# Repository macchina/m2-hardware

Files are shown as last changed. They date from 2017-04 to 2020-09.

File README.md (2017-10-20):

# Macchina M2

The Macchina M2 is a open-source, programmable interface with hardware support for most automotive protocols including CAN, SWCAN, LIN, J1850PWM, ISO9141, and KWP2000.

This repository contains open sourced files for to the M2 hardware.  The **M2** folder contains files for the retail version of the M2.  The **M2-B** contains the files for the beta board that was produced in limited numbers and sent to members of the Developer Program.

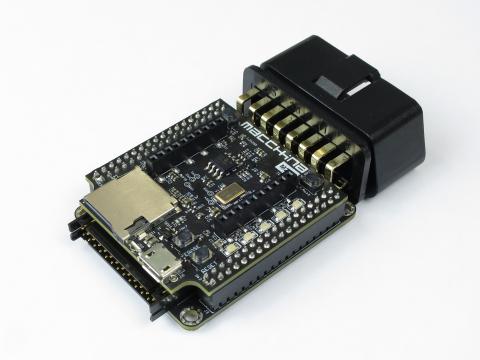
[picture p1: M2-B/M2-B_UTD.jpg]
Under-the-dash model


The under-the-dash model, pictured above, plugs into your car's OBD2 port.  The Macchina M2 is also available in an under-the-hood model.

The files in this repository are released under the [Creative Commons Attribution-ShareAlike 4.0 International (CC BY-SA) license](LICENSE).

To order visit https://www.macchina.cc/catalog

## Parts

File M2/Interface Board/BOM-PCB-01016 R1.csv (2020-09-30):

# | Quantity | PartType | Designator | Description | Footprint | MANUFACTURER | MANUFACTURER # | DISTRIBUTOR | DISTRIBUTOR #
1 | 2 | 9.0pF | C47, C48 | CAP CER 9.0PF 50V NP0 0402 | 0402_N2A-C | Murata Electronics North America | GRM1555C1H9R0CA01D | Digi-Key | 490-8232-1-ND
2 | 2 | 22pF | C17, C20 | CAP CER 22PF 50V C0G/NP0 0402 | 0402_N2A-C | Murata Electronics North America | GJM1555C1H220JB01D | Digi-Key | 490-14444-1-ND
3 | 5 | 100pF | C31, C32, C37, C38, C49 | CAP CER 100PF 5% 50V NP0 0402 | 0402_N2A-C | AVX Corporation | 04025A101JAT2A | Digi-Key | 478-1082-1-ND
4 | 3 | 220pF | C28, C30, C45 | CAP CER 220PF 50V 5% NP0 0402 | 0402_N2A-C | Panasonic Electronic Components | ECJ-0EC1H221J | Digi-Key | PCC221CQCT-ND
5 | 3 | 4.7nF | C10, C36, C42 | CAP CER 4700PF 25V X7R 0402 | 0402_N2A-C | Murata Electronics North America | GRM155R71E472KA01D | Digi-Key | 490-1309-1-ND
6 | 1 | 0.01uF | C4 | CAP CER .01UF 50V X7R 0402 | 0402_N2A-C | Kemet | C0402C103K5RACTU | Digi-Key | 399-3066-1-ND
7 | 20 | 0.1uF | C1, C3, C7, C8, C12, C18, C19, C21, C22, C24, C25, C26, C27, C29, C33, C34, C39, C40, C44, C46 | CAP CER .10UF 25V X5R 0402 | 0402_N2A-C | Taiyo Yuden | TMK105BJ104KV-F | Digi-Key | 587-1456-1-ND
8 | 1 | 1.0uF | C9 | CAP CER 1UF 10V X5R 0402 | 0402_N2A-C | Murata Electronics North America | GRM155R61A105KE15D | Digi-Key | 490-3890-1-ND
9 | 6 | 10uF | C13, C14, C15, C16, C35, C41 | CAP CER 10UF 16V X5R 0603 | 0603_N2A-C | Murata Electronics North America | GRT188R61C106KE13D | Digi-Key | 490-12317-1-ND
10 | 4 | 10uF | C2, C5, C6, C43 | CAP CER 10UF 25V X5R 0805 | 0805_N2A-C | Murata Electronics North America | GRM21BR61E106KA73K | Digi-Key | 490-5523-1-ND
11 | 2 | 0.0 | R5, R9 | RES 0.0 OHM 5% 1/10W 0603 | 0603_N2A-R | Vishay Dale | CRCW06030000Z0EA | Digi-Key | 541-0.0GCT-ND
12 | 7 | 0.0 | R7, R126, R127, R130, R131, R137, R138 | RES SMD 0 OHM JUMPER 1/16W 0402 | 0402_N2A-R | Vishay Dale | CRCW04020000Z0ED | Digi-Key | 541-0.0JCT-ND
13 | 1 | 0.010 | R18 | RES SMD 0.01 OHM 1% 1/4W 0805 | 0805_N2A-R | Yageo | PF0805FRM7W0R01L | Digi-Key | 311-0.01NUCT-ND
14 | 4 | 60.4 | R128, R129, R132, R133 | RES 60.4 OHM 1% 1/16W 0402 | 0402_N2A-R | Vishay Dale | CRCW040260R4FKED | Digi-Key | 541-60.4LCT-ND
15 | 1 | 240 | R104 | RES 240 OHM 1% 1/16W 0402 | 0402_N2A-R | Vishay Dale | CRCW0402240RFKED | Digi-Key | 541-240LCT-ND
16 | 1 | 374 | R109 | RES 374 OHM 1% 1/16W 0402 | 0402_N2A-R | Vishay Dale | CRCW0402374RFKED | Digi-Key | 541-374LCT-ND
17 | 8 | 470 | R16, R29, R42, R55, R75, R88, R101, R108 | RES SMD 470 OHM 1% 1/16W 0402 | 0402_N2A-R | Yageo | RC0402FR-07470RL | Digi-Key | 311-470LRCT-ND
18 | 1 | 866 | R106 | RES 866 OHM 1% 1/16W 0402 | 0402_N2A-R | Vishay Dale | CRCW0402866RFKED | Digi-Key | 541-866LCT-ND
19 | 10 | 1.00K | R21, R23, R30, R43, R56, R77, R90, R103, R122, R134 | RES SMD 1K OHM 1% 1/16W 0402 | 0402_N2A-R | Yageo | RC0402FR-071KL | Digi-Key | 311-1.00KLRCT-ND
20 | 1 | 2.00K | R117 | RES 2.00K OHM 1% 1/16W 0402 | 0402_N2A-R | Vishay Dale | CRCW04022K00FKED | Digi-Key | 541-2.00KLCT-ND
21 | 7 | 2.20K | R33, R46, R59, R72, R85, R98, R107 | RES SMD 2.20K OHM 1% 1/16W 0402 | 0402_N2A-R | Yageo | RC0402FR-072K2L | Digi-Key | 311-2.20KLRCT-ND
22 | 2 | 4.70K | R3, R20 | RES 4.70K OHM 1% 1/16W 0402 | 0402_N2A-R | Vishay Dale | CRCW04024K70FKED | Digi-Key | 541-4.70KLCT-ND
23 | 1 | 6.49K | R135 | RES 6.49K OHM 1% 1/8W 0805 | 0805_N2A-R | Yageo | RC0805FR-076K49L | Digi-Key | 311-6.49KCRCT-ND
24 | 1 | 8.06K | R118 | RES SMD 8.06K OHM 1% 1/16W 0402 | 0402_N2A-R | Yageo | RC0402FR-078K06L | Digi-Key | 311-8.06KLRCT-ND
25 | 1 | 8.87K | R8 | RES SMD 8.87K OHM 1% 1/16W 0402 | 0402_N2A-R | Yageo | RC0402FR-078K87L | Digi-Key | 311-8.87KLRCT-ND
26 | 32 | 10.0K | R2, R4, R22, R24, R27, R31, R32, R40, R44, R45, R53, R57, R58, R71, R74, R84, R87, R97, R100, R105, R110, R111, R113, R114, R115, R119, R120, R121, R123, R136, R139, R140 | RES SMD 10K OHM 1% 1/16W 0402 | 0402_N2A-R | Yageo | RC0402FR-0710KL | Digi-Key | 311-10.0KLRCT-ND
27 | 2 | 22.1K | R12, R25 | RES SMD 22.1K OHM 1% 1/16W 0402 | 0402_N2A-R | Yageo | RC0402FR-0722K1L | Digi-Key | 311-22.1KLRCT-ND
28 | 1 | 27.0K | R6 | RES SMD 27.0K OHM 1% 1/16W 0402 | 0402_N2A-R | Yageo | RC0402FR-0727KL | Digi-Key | 311-27.0KLRCT-ND
29 | 20 | 100K | R15, R17, R19, R28, R34, R41, R47, R54, R60, R67, R73, R76, R80, R86, R89, R93, R99, R102, R112, R116 | RES SMD 100K OHM 1% 1/16W 0402 | 0402_N2A-R | Yageo | RC0402FR-07100KL | Digi-Key | 311-100KLRCT-ND
30 | 1 | 124K | R11 | RES SMD 124K OHM 1% 1/16W 0402 | 0402_N2A-R | Yageo | RC0402FR-07124KL | Digi-Key | 311-124KLRCT-ND
31 | 1 | 1.0M | R1 | RES 1.00M OHM 1% 1/16W 0402 | 0402_N2A-R | Yageo | RC0402FR-071ML | Digi-Key | 311-1.00MLRCT-ND
32 | 1 | 60R | FB1 | FERRITE BEAD 60 OHM 0603 1LN | 0603_N2A-FB | Wurth ELectronics Inc. | 74279228600 | Digi-Key | 732-6119-1-ND
33 | 1 | 3.3uH | L1 | FIXED IND 3.3UH 3.3A 27 MOHM SMD | SRN5040 | Bourns Inc. | SRN5040-3R3M | Digi-Key | SRN5040-3R3MCT-ND
34 | 1 | 47uH | L4 | FIXED IND 47UH 170mA 3.7 OHM SMD | 0805_N2A-L | TDK Corporation | MLZ2012M470WT000 | Digi-Key | 445-6400-1-ND
35 | 6 | 0.75A | F2, F3, F4, F5, F6, F7 | PTC 16V 0.75Ahold 1.5Atrip 1206 | 1206-F1 | Ruilon | SMD1206P075TF/16 | Ruilon | SMD1206P075TF/16
36 | 1 | 2.6A | F1 | PTC RESTTBLE 2.6A 16V CHIP 1812 | 1812_N2A-F | Bel Fuse Inc | 0ZCG0260BF2B | Digi-Key | 507-1780-1-ND
37 | 2 | 36mA | F8, F9 | PTC 16V 36mAhold 91mAtrip 0603 | 0603_N2A-F | Murata Electronics North America | PRG18BB330MS1RB | Digi-Key | 490-12121-1-ND
38 | 6 | 16.2V | V1, V2, V3, V4, V5, V6 | VARISTOR 16.2V 20A 0402 | 0402_N2A-V | Bourns Inc. | CG0402MLA-14KG | Digi-Key | CG0402MLA-14KGCT-ND
39 | 1 | B340LA | D1 | DIODE SCHOTTKY 40V 3A SMA 2.3 MM HEIGHT | SMA | Diodes Incorporated | B340LA-13-F | Digi-Key | B340LA-FDICT-ND
40 | 1 | SMBJ14A | D2 | TVS DIODE 14VWM 23.2VC SMB | SMB | Littlefuse Inc. | SMBJ14A | Digi-Key | SMBJ14ALFCT-ND
41 | 1 | MM3Z16V | D3 | DIODE ZENER 16V 300MW SOD323 | SOD-323 | ON Semiconductor | MM3Z16VT1G | Digi-Key | MM3Z16VT1GOSCT-ND
42 | 1 | 3.3V | D4 | DIODE ZENER 3.3V 300MW SOD523 | SOD-523F | Diodes Incorporated | BZT52C3V3T-7 | Digi-Key | BZT52C3V3T-7DICT-ND
43 | 2 | SP1002-02 | D11, D12 | TVS DIODE 6VWM 16VC SC70-5 | SC-70-5 | Littlefuse Inc. | SP1002-02JTG | Digi-Key | F4238CT-ND
44 | 6 | BAT54 | D5, D6, D7, D8, D9, D10 | DIODE SCHOTTKY 30V 200MA SOD523F | SOD-523F | Fairchild Semiconductor | BAT54XV2 | Digi-Key | BAT54XV2CT-ND
45 | 1 | TVS 22V | V7 | TVS DIODE 22V 40VC SC70-3 | SOT-323 | ON Semiconductor | MMBZ27VAWT1G | Digi-Key | MMBZ27VAWT1GOSCT-ND
46 | 2 | IRFTS9342 | Q1, Q6 | MOSFET P-CH 30V 5.8A 6TSOP | TSOP6-6 | Infineon Technologies | IRFTS9342TRPBF | Digi-Key | IRFTS9342TRPBFCT-ND
47 | 1 | MMBT3906W | Q2 | TRANS PNP 40V 0.2A SOT323 | SOT-323 | On Semiconductor | MMBT3906WT1G | Digi-Key | MMBT3906WT1GOSCT-ND
48 | 5 | IRLML5203 | Q3, Q4, Q8, Q12, Q16 | MOSFET P-CH 30V 3A SOT-23 | SOT-23 | International Rectifier | IRLML5203TRPBF | Digi-Key | IRLML5203TRPBFCT-ND
49 | 1 | FSB660A | Q32 | TRANSISTOR PNP 60V 2A SSOT-3 | SOT-23 | Fairchild Semiconductor | FSB660A | Digi-Key | FSB660ACT-ND
50 | 4 | BSS138PW | Q5, Q33, Q34, Q35 | MOSFET N-CH 60V 320MA SOT323 | SOT-323 | NXP Semiconductor | BSS138PW,115 | Digi-Key | 568-10309-1-ND
51 | 7 | MMBT3904 | Q7, Q9, Q13, Q17, Q23, Q27, Q31 | TRANS NPN 40V 0.2A SOT323 | SOT-323 | ON Semiconductor | MMBT3904WT1G | Digi-Key | MMBT3904WT1GOSCT-ND
52 | 3 | IRLML0060 | Q22, Q26, Q30 | MOSFET N-CH 60V 2.7A SOT-23-3 | SOT-23 | International Rectifier | IRLML0060TRPBF | Digi-Key | IRLML0060TRPBFCT-ND
53 | 1 | TPS54328 | U1 | IC REG BUCK ADJ 3A SYNC 8SOPWR | SO-8-1 | Texas Instruments | TPS54328DDAR | Digi-Key | 296-28080-1-ND
54 | 2 | LM393 | U3, U6 | IC COMPARATOR DUAL 8-UFSON 2X2 | DFN-8-1 | STMicroelectronics | LM393QT | Digi-Key | 497-11126-1-ND
55 | 2 | TJA1051 | U9, U10 | IC TXRX CAN HIGH SPEED 8HVSON | HVSON-8-1 | NXP Semiconductors | TJA1051TK/3,118 | Digi-Key | 568-8686-1-ND
56 | 1 | LM317L | U5 | IC REG LDO ADJ 0.1A SOT89-3 | SOT-89 | Texas Instruments | LM317LCPK | Digi-Key | 296-26093-1-ND
57 | 1 | TH8056 | U11 | IC TXRX CAN SGL WIRE 8SOIC | SO-8 | MELEXIS | TH8056KDC-AAA-008-TU | Digi-Key | TH8056KDC-AAA-008-TU-ND
58 | 1 | MCP2515 | U12 | IC CAN CONTROLLER W/SPI 20TSSOP | TSSOP-20 | Microchip Technology | MCP2515T-I/ST | Digi-Key | MCP2515T-I/STCT-ND
59 | 1 | ZXCT1109 | U2 | IC CURR MONITOR HIGH SIDE SOT23 | SOT-23 | Diodes Incorporated | ZXCT1109SA-7 | Digi-Key | ZXCT1109SA-7DICT-ND
60 | 2 | TJA1027 | U7, U8 | IC TXRX LIN 2.2/SAE J2602 8-HVSON | HVSON-8-1 | NXP Semiconductors | TJA1027TK/20/1J | Digi-Key | 568-13612-1-ND
61 | 1 | 16MHz | X1 | CRYSTAL 16.0000MHZ 10PPM 9PF 60 OHM | XTAL-SMD2.5X3.2 | EPSON | TSX-3225 16.0000MF18X-AC3 | Digi-Key | SER3636CT-ND
62 | 1 | OBD2 | J1 | OBD2 RT-ANGLE MALE PIN | OBD2_RT_MALE | Macchina | CCBDM205 | Macchina | CCBDM205
63 | 2 | CONN HDR36 | J3, J4 | CONN HDR BRKWAY 36POS 2MM 30GOLD | 3-5176264-2 | TE | 3-5176264-2 | Digi-Key | 3-5176264-2-ND
64 | 1 | HDR26 | J5 | CONN HEADER 26POS RA THOLE | HDR26RA2MM | HIROSE | DF11-26DP-2DS(52) | Digi-Key | H2876-ND
 | STICKER

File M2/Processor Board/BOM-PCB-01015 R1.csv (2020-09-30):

# | Quantity | PartType | Designator | Description | Footprint | MANUFACTURER | MANUFACTURER # | DISTRIBUTOR | DISTRIBUTOR #
1 | 5 | 22pF | C9, C10, C13, C14, C16 | CAP CER 22PF 50V C0G/NP0 0402 | 0402_N2A-C | Murata Electronics North America | GJM1555C1H220JB01D | Digi-Key | 490-14444-1-ND
2 | 32 | 0.1uF | C1, C2, C4, C6, C8, C15, C17, C20, C21, C22, C23, C24, C25, C26, C27, C28, C29, C30, C31, C32, C33, C34, C35, C38, C39, C40, C42, C43, C46, C47, C49, C50 | CAP CER .10UF 25V X5R 0402 | 0402_N2A-C | Taiyo Yuden | TMK105BJ104KV-F | Digi-Key | 587-1456-1-ND
3 | 11 | 10uF | C3, C5, C7, C11, C12, C19, C36, C37, C41, C44, C45 | CAP CER 10UF 6.3V X5R 0603 | 0603_N2A-C | Murata Electronics North America | GRM188R60J106ME47D | Digi-Key | 490-3896-1-ND
4 | 1 | 100uF | C18 | CAP CER 100UF 6.3V X5R 1206 | 1206_N2A-C | Taiyo Yuden | JMK316BBJ107MLHT | Digi-Key | 587-3716-1-ND
5 | 6 | 0.0 | R12, R14, R16, R20, R22, R40 | RES SMD 0 OHM Jumper 1/16W 0402 | 0402_N2A-R | Yageo | RC0402FR-070RL | Digi-Key | 311-0.0LRCT-ND
6 | 2 | 39.0 | R4, R5 | RES SMD 39 OHM 1% 1/10W 0402 | 0402_N2A-R | Panasonic Electronic Components | ERJ-2RKF39R0X | Digi-Key | P39.0LCT-ND
7 | 1 | 374 | R35 | RES 374 OHM 1% 1/16W 0402 | 0402_N2A-R | Vishay Dale | CRCW0402374RFKED | Digi-Key | 541-374LCT-ND
8 | 1 | 470 | R44 | RES SMD 470 OHM 1% 1/16W 0402 | 0402_N2A-R | Yageo | RC0402FR-07470RL | Digi-Key | 311-470LRCT-ND
9 | 10 | 1.00K | R11, R17, R23, R36, R37, R38, R45, R46, R47, R49 | RES 1.0K OHM 1/10W 1% 0402 SMD | 0402_N2A-R | Panasonic Electronic Components | ERJ-2RKF1001X | Digi-Key | P1.00KLCT-ND
10 | 1 | 2.20K | R48 | RES 2.2K OHM 1/10W 1% 0402 SMD | 0402_N2A-R | Panasonic Electronic Components | ERJ-2RKF2201X | Digi-Key | P2.20KLCT-ND
11 | 1 | 6.80K | R6 | RES SMD 6.8K OHM 1% 1/10W 0402 | 0402_N2A-R | Panasonic Electronic Components | ERJ-2RKF6801X | Digi-Key | P6.80KLCT-ND
12 | 14 | 10.0K | R2, R8, R27, R28, R29, R32, R34, R41, R42, R43, R50, R51, R52, R54 | RES SMD 10K OHM 1% 1/10W 0402 | 0402_N2A-R | Panasonic Electronic Components | ERJ-2RKF1002X | Digi-Key | P10.0KLCT-ND
13 | 5 | 100K | R1, R9, R10, R33, R53 | RES SMD 100K OHM 1% 1/10W 0402 | 0402_N2A-R | Panasonic Electronic Components | ERJ-2RKF1003X | Digi-Key | P100KLCT-ND
14 | 2 | 1.0M | R7, R39 | RES SMD 1M OHM 5% 1/16W 0402 | 0402_N2A-R | Yageo | RC0402JR-071ML | Digi-Key | 311-1.0MJRCT-ND
15 | 5 | 30R | FB1, FB2, FB3, FB4, FB5 | FERRITE BEAD 30 OHM 0402 1LN | 0402_N2A-FB | Samsung Electro-Mechanics | CIC05P300NC | Digi-Key | 1276-6392-1-ND
16 | 1 | 0.5A | F1 | PTC RESETTABLE 8V 500MA 1206 | 1206_N2A-F | Bel Fuse Inc. | 0ZCJ0050FF2G | Digi-Key | 507-1802-2-ND
17 | 1 | PD3S130L | D1 | DIODE SCHOTTKY 30V 1A POWERDI323 | PDI-323 | Diodes Inc | PD3S130L-7 | Digi-Key | PD3S130LDICT-ND
18 | 1 | BAT54CW | D2 | DIODE ARRAY SCHOTTKY 30V SOT323 | SOT-323 | Nexperia USA Inc. | BAT54CW,115 | Digi-Key | 568-1613-1-ND
19 | 1 | RED | D3 | LED RED DIFFUSED 0805 SMD | LED_0805-RED | OSRAM Opto Semiconductors Inc. | LS R976-NR-1 | Digi-Key | 475-1278-1-ND
20 | 3 | YEL | D4, D5, D6 | LED YELLOW DIFFUSED 0805 SMD | LED_0805-YEL | OSRAM Opto Semiconductors Inc. | LY R976-PS-36 | Digi-Key | 475-2560-1-ND
21 | 1 | GRN | D7 | LED GRN DIFFUSED 0805 SMD | LED_0805-GRN | OSRAM Opto Semiconductors Inc. | LG R971-KN-1 | Digi-Key | 475-1410-1-ND
22 | 1 | RGB | D8 | LED RGB CLEAR CHIP SMD R/A | RGB_LED_SMT_RA | Kingbright | APFA3010SEEZGQBDC | Digi-Key | 754-1649-1-ND
23 | 1 | TPD4S012 | Z1 | IC 4CH ESD SOLUTION W/CLAMP 6SON | USON6-H06 | Texas Instruments | TPD4S012DRYR | Digi-Key | 296-24244-1-ND
24 | 1 | FDN340 | Q1 | MOSFET P-CH 20V 2A SSOT3 | SOT-23-3 | Fairchild Semiconductor | FDN340P | Digi-Key | FDN340PCT-ND
25 | 1 | MMBT3904W | Q2 | TRANS NPN 40V 0.2A SOT323 | SOT-323 | ON Semiconductor | MMBT3904WT1G | Digi-Key | MMBT3904WT1GOSCT-ND
26 | 1 | MMBT3906W | Q3 | TRANS PNP 40V 0.2A SOT323 | SOT-323 | On Semiconductor | MMBT3906WT1G | Digi-Key | MMBT3906WT1GOSCT-ND
27 | 1 | ATSAM3X8EA | U1 | IC MCU 32BIT 512KB FLASH 144LQFP | LQFP-144-MIN | ATMEL | ATSAM3X8EA-AU | Digi-Key | ATSAM3X8EA-AU-ND
28 | 1 | 24LC32AT | U2 | IC EEPROM 32K I2C SOT23-5 | SOT-23-5 | MICROCHIP | 24LC32AT-I/OT | Digi-Key | 24LC32AT-I/OTTR-ND
29 | 1 | LD39200 | U3 | IC REG LINEAR 3.3V 2A 6DFN | VDFN-6-EP_(3x3) | STMicroelectronics | LD39200PU33R | Digi-Key | 497-15229-1-ND
30 | 1 | 12MHz | X1 | CRYSTAL 12.0000MHZ 18PF SMD | XTAL_6x3.6 | Abracon LLC | ABMM2-12.000MHZ-E2-T | Digi-Key | 535-9631-1-ND
31 | 1 | 32.768kHz | X2 | CRYSTAL 32.768KHZ 12.5PF SMD | XTAL-AB26TRQ | Abracon LLC | AB26TRQ-32.768KHZ-T | Digi-Key | 535-12051-1-ND
32 | 4 | PTS810 | SW1, SW2, SW3, SW4 | SWITCH TECTILE SPST-NO 0.05A 16V | TACT_42_32 | C&K | PTS810 SJK 250 SMTR LFS | Digi-Key | CKN10503CT-ND
33 | 2 | CONN RCPT36 | J1, J2 | RCPT, 2.0MM, 36P, VRT MT, 8 AU" | 4-1734506-1 | TE Connectivity AMP Connectors | 4-1734506-1 | Digi-Key | A118476-ND
34 | 1 | 19850 | J3 | CONN SD SMT w/DETECT_SW | SD_19850 | 4UCON | 19850
35 | 1 | SIP 10 | J4, J5 | SIP 10 Pin SMT 2mm | SIP10-SMT | WCON Hardware Electronics Co., LTD | 2243-1 10 M XX CUN T 1
36 | 1 | USB MICRO AB | J6 | CONN RCPT MICRO USB AB 5P SMD RA | USB MICRO MOL-0475890001-A | Molex | 0475890001 | Digi-Key | WM17143CT-ND

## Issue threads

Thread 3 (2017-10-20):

Where are the actual source files?

s-hemer, 2017-10-20:
Actually, with the schematics and layer pdfs one can (thoughly) understand/follow the design and with the STEP file one may even be able to reproduce it but for being fully open-source, in my opinion, you should also publish the real KiCad/Eagle/whatever source file. The hard guys would maybe even argue to use a publicly accessible tool like KiCad so everyone can easily understand/follow the design and may also modify.

Regards

Steffen

s-hemer, 2017-11-07:
Just checked again: you announced this also at https://www.macchina.cc/m2-introduction

> To that end, we will release all design documentation to our development team once our campaign is over and we begin shipping beta units.

I'd really appreciate this as it was one big reason to back your Kickstarter campaign!

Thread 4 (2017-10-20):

Using MCP2515 as CAN interface

s-hemer, 2017-10-20:
After receiving my Macchina Interface-only board I backed in the Kickstarter campaign, I am a little disappointed that I cannot switch the MCP2515 to use it for SWCAN or standard CAN. I am no expert in SWCAN but wouldn't it be possible to just switch the transceiver via some jumpers to one of the two transceivers that are used with the SAM-internal CAN controllers?

(This relates also to the forum entry https://forum.macchina.cc/t/raspberry-pi-wiring-and-libraries/260/7)

Regards

Steffen

redheadedrod, 2017-10-21:
You are likely to get a better response on the forum.

adamvoss, 2017-10-21:
> You are likely to get a better response on the forum.

I agree so am closing this.  @s-hemer please start a discussion on the forum.

s-hemer, 2017-10-24:
This is in my opinion a deficit of the board that might be changed in a future version ??!! So it should be discussed here as an issue. That's what it is for, the issue tracker. For the forum, I would need another damn login and there people may discuss things like "How do I use this and that".
Maybe you provide the real sources as mentioned in the other issue then I can check on my own what is possible and what not.
Thanks for the support.

adamvoss, 2017-10-24:
I am sorry for your frustration, I would like to see you get a response to your request, which is why both both redheadedrod and I directed you to the forum; because that is where the people who are likely to respond will read.

Regarding the original post, I perhaps missed that it was supposed to be a change request for future iterations of the board.  I saw it as a question of whether it would be possible to switch the transceiver using jumpers and the audience that will answer usage questions is at the forum.

redheadedrod, 2017-10-25:
Git issues generally are on a specific software piece that can be dealt with. Future plans and that sort of thing should be discussed on the forum. Yes it requires another account but those serious about using this stuff shouldn't have an issue there. The issue with issues or comments here is that they will be missed in the future. At least on the forum it will come up in searches much easier and such. Won't get lost in the dust.

Note I am not associated with Macchina, just an interested party.

Closed 2017-10-21.

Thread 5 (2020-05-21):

Circuit is not reverse-polarity protected

yope, 2020-05-21:
No idea if feedback on the schematics is desired, but since I am looking at them I will just file here all the (potential) issues and possible improvements I find, in case anybody is interested.

The tranzorb D2 (JMBJ14A) is unidirectional. Although there is D1 probably intended to protect the circuit from reverse-polarity damage, it does not work due to D2.
In case the circuit happens to be connected to reversed polarity, D2 will short-circuit, and race against the fuse in which one will die first. Tranzorbs are designed to hard short-circuit if blown, so the fuse will also go in the end. Note that the tranzorb will stay in short circuit, so replacing the fuse won't help.

The next problem is VIN2, which isn't protected against reverse polarity. Q6 will conduct through the body diode, and so will all the output transistors and depending on the load connected to them, other damage might occur.

So either D1 is useless and no RP protection is intended, or these issues need fixing.

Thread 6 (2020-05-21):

D2 clamp voltage potentially too low

yope, 2020-05-21:
D2 hold-off voltage is 14V. Board net voltage may reach up to 15V in some cases, and disturbances may go much higher than that.
D2 is of type SMBJ14A. This type has a break-down voltage of minimum 15.6V, but that is already at a reverse current of 1A. It will be dissipating more than 15W at that time which it won't survive for long.
Even at voltages much lower than that, significant reverse-current can flow, and D2 may get hot or even burn out.
SMBJ18CA would be a much better suited alternative.

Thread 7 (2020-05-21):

Possible improvement of 5V regulator protection

yope, 2020-05-21:
The 5V regulator (TPS54328) can operate with a maximum input voltage of 18V (20V absolute maximum). While chances of exceeding that voltage are not that high most of the time, and for occasional connection to a car it will probably be fine, it can be improved.
There is the over-voltage protection circuit comprised of Q2, Q1 and D3, which intends to limit the input voltage to 17V approximately, but it isn't really necessary if a different regulator is used.

The best solution would be a full-blown automotive-spec regulator, like the LM53603. This chip can sustain even moderate load-dump conditions and would make this circuit suitable for permanent installation inside a car. D2 would need to be chose of type SMBJ39CA or similar. Also take care of capacitor voltages. Ceramic capacitors can usually withstand 40% overvoltage for a short while without damage.

If that's too expensive, even the much cheaper TPS54339 might give a lot more head-room, and lets you avoid the OVP circuit (Q2, Q1 and D3), while also making the selection of D2 less critical.

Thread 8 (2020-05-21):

Possible analog input protection improvements

yope, 2020-05-21:
The analog input dividers (GPIO1-6) have some unspecified protection devices (V1-V6).
What are they? (Varistors?) If these devices start conducting at 16.2V, in case of over-voltage these devices will get destroyed depending on allowed input current.
A much better way of protecting the delicate analog inputs of the processor is to use 3.3V ESD protection devices (or better zener diodes) on the CPU pins and increase the impedance of the voltage divider as much as possible within the design constraints. The current that needs to be clamped at the 3.3V devices (and in part possibly through the clamping diodes of the CMOS inputs) is minimal and won't destroy anything. Try to make the top resistors (R32...) of each divider 22k or higher if possible. Also consider some filter capacitance on the GPIO_ANA side of the divider. High frequency disturbance can be treacherous ;-)

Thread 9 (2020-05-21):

Capacitive load of CAN bus possibly too high

yope, 2020-05-21:
I am not very familiar with the automotive CAN standards (coming from agricultural  background), but the capacitance on the CAN lines (100pF, C31, C32, C37, C38) seem extremely high.
I suggest removing them.
Probably this won't be an issue if all other ECU's on the bus have much lower capacitance, but imagine a fully loaded CAN bus (32 nodes) each of them putting 100+pF on the CAN wires... ;-)

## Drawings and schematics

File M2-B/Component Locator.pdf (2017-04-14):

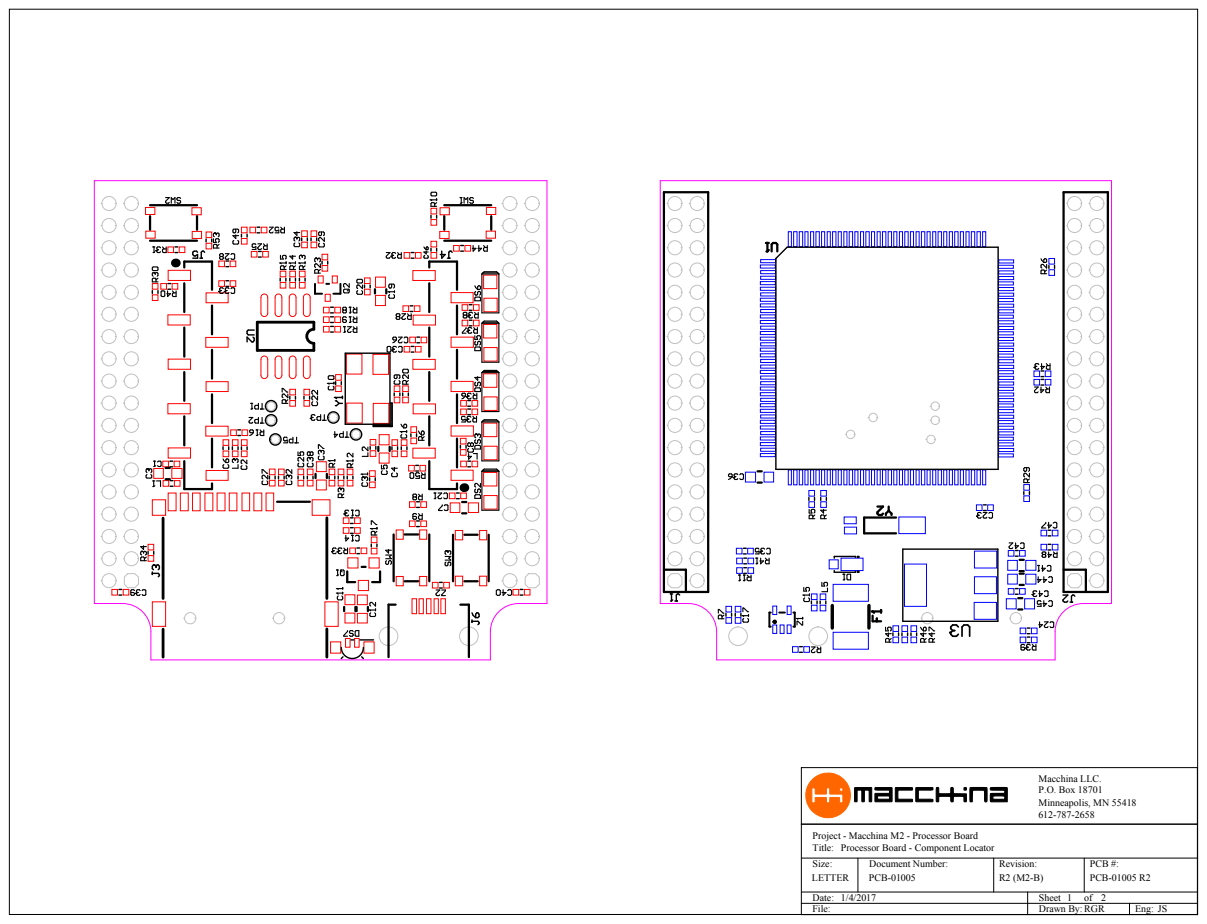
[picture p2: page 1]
Size:; Document Number:; Revision:; PCB #:; Sheet Drawn By:; Eng:; LETTER; PCB-01005; PCB-01005 R2; RGR; P.O. Box 18701; Macchina LLC.; Minneapolis, MN 55418

Project - Macchina M2 - Processor Board
Title:
Date:
File:

Processor Board - Component Locator

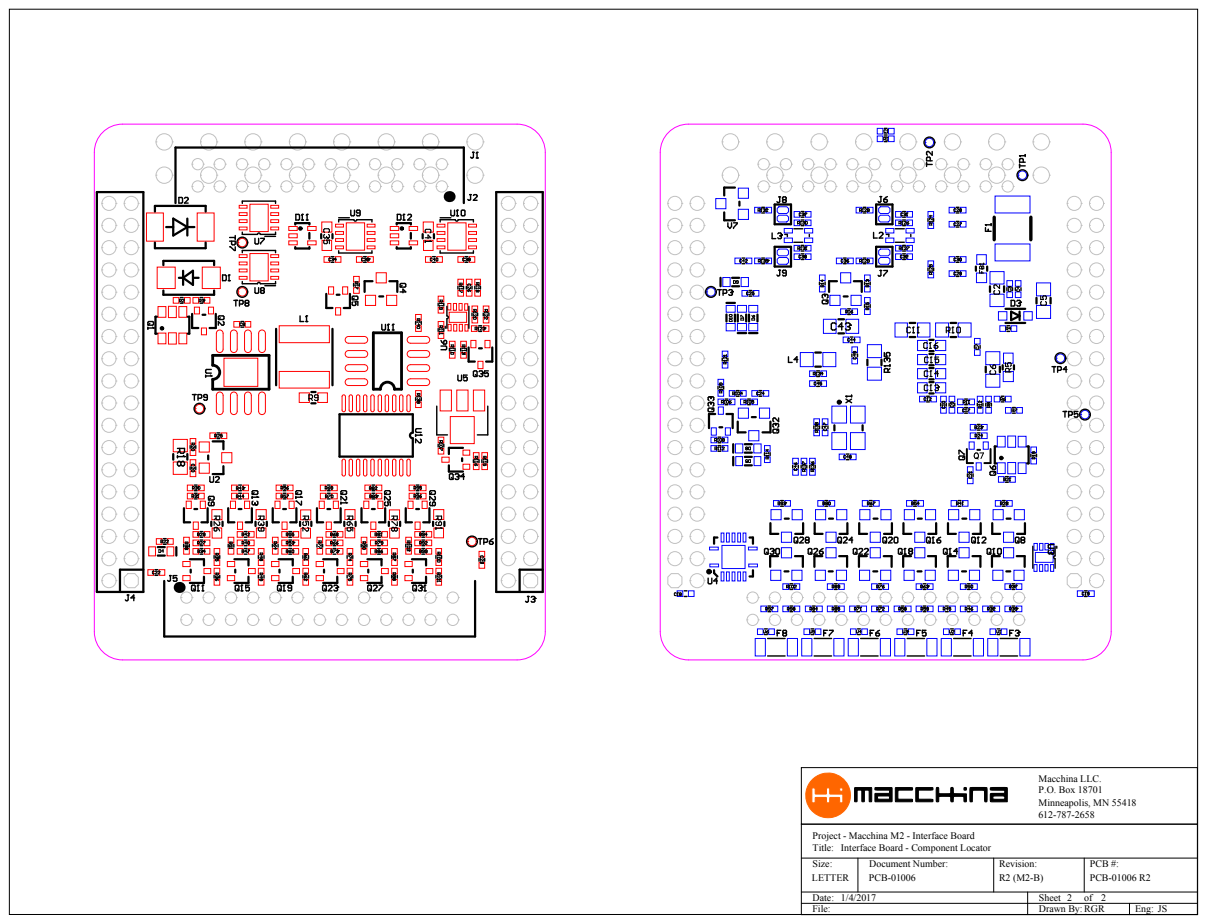
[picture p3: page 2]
Size:; Document Number:; Revision:; PCB #:; Sheet Drawn By:; Eng:; LETTER; PCB-01006; PCB-01006 R2; RGR; P.O. Box 18701; Macchina LLC.; Minneapolis, MN 55418

Project - Macchina M2 - Interface Board
Title:
Date:
File:

Interface Board - Component Locator

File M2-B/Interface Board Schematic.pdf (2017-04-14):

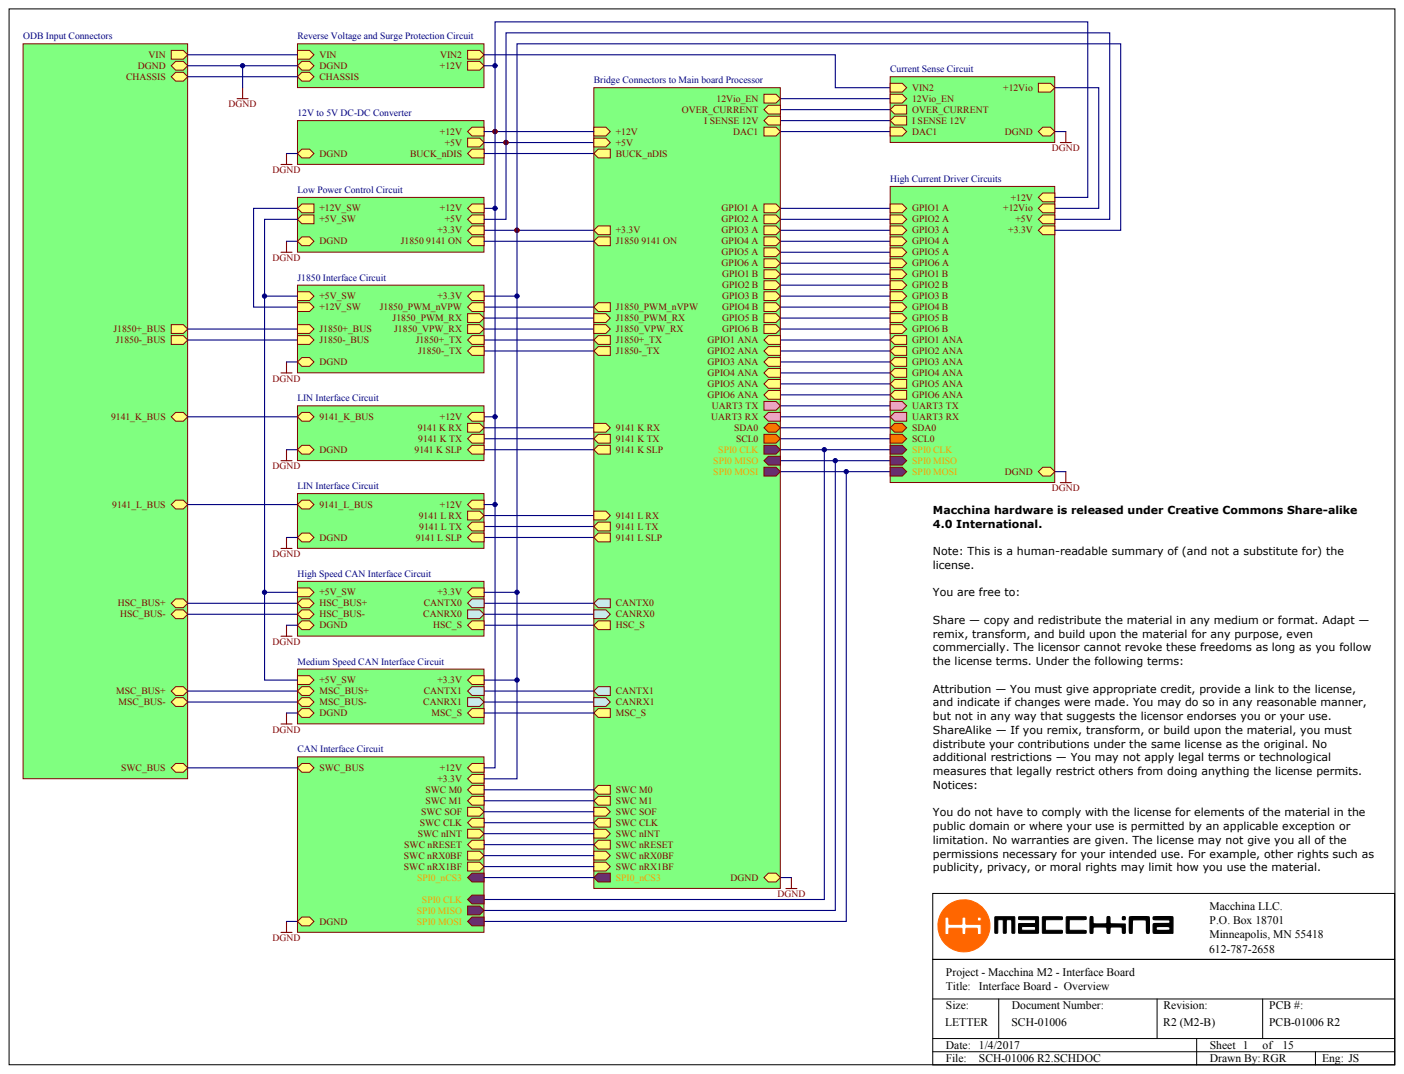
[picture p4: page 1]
J1850-_BUS; J1850+_BUS; 9141_L_BUS; 9141_K_BUS; SWC_BUS; MSC_BUS-; MSC_BUS+; HSC_BUS+ HSC_BUS-; VIN DGND CHASSIS; DGND; VIN2; +5V BUCK_nDIS; GPIO5 A GPIO6 A; J1850_PWM_RX; MSC_S; CANTX0; UART3 TX; CANTX1; SPI0_nCS3; GPIO5 B GPIO6 B; 12Vio_EN; J1850_VPW_RX; HSC_S; SWC CLK; SWC nRESET; CANRX0; UART3 RX SDA0; GPIO1 A; GPIO2 B; GPIO3 A GPIO4 A; GPIO5 ANA GPIO6 ANA; SWC nINT; CANRX1; SPI0 MISO SPI0 MOSI; SWC nRX0BF; GPIO1 B; GPIO2 A; GPIO3 B GPIO4 B; GPIO1 ANA GPIO2 ANA GPIO3 ANA GPIO4 ANA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

ODB Input Connectors

Reverse Voltage and Surge Protection Circuit
VIN
CHASSIS

Bridge Connectors to Main board Processor

12V to 5V DC-DC Converter DGND

High Current Driver Circuits

Macchina hardware is released under Creative Commons Share-alike
4.0 International.

Note: This is a human-readable summary of (and not a substitute for) the
license.

You are free to:

Share — copy and redistribute the material in any medium or format. Adapt —
remix, transform, and build upon the material for any purpose, even
commercially. The licensor cannot revoke these freedoms as long as you follow
the license terms. Under the following terms:

Attribution — You must give appropriate credit, provide a link to the license,
and indicate if changes were made. You may do so in any reasonable manner,
but not in any way that suggests the licensor endorses you or your use.
ShareAlike — If you remix, transform, or build upon the material, you must
distribute your contributions under the same license as the original. No
additional restrictions — You may not apply legal terms or technological
measures that legally restrict others from doing anything the license permits.
Notices:

You do not have to comply with the license for elements of the material in the
public domain or where your use is permitted by an applicable exception or
limitation. No warranties are given. The license may not give you all of the
permissions necessary for your intended use. For example, other rights such as
publicity, privacy, or moral rights may limit how you use the material.

Project - Macchina M2 - Interface Board
Title:
Interface Board - Overview
Date:
File:
SCH-01006 R2.SCHDOC

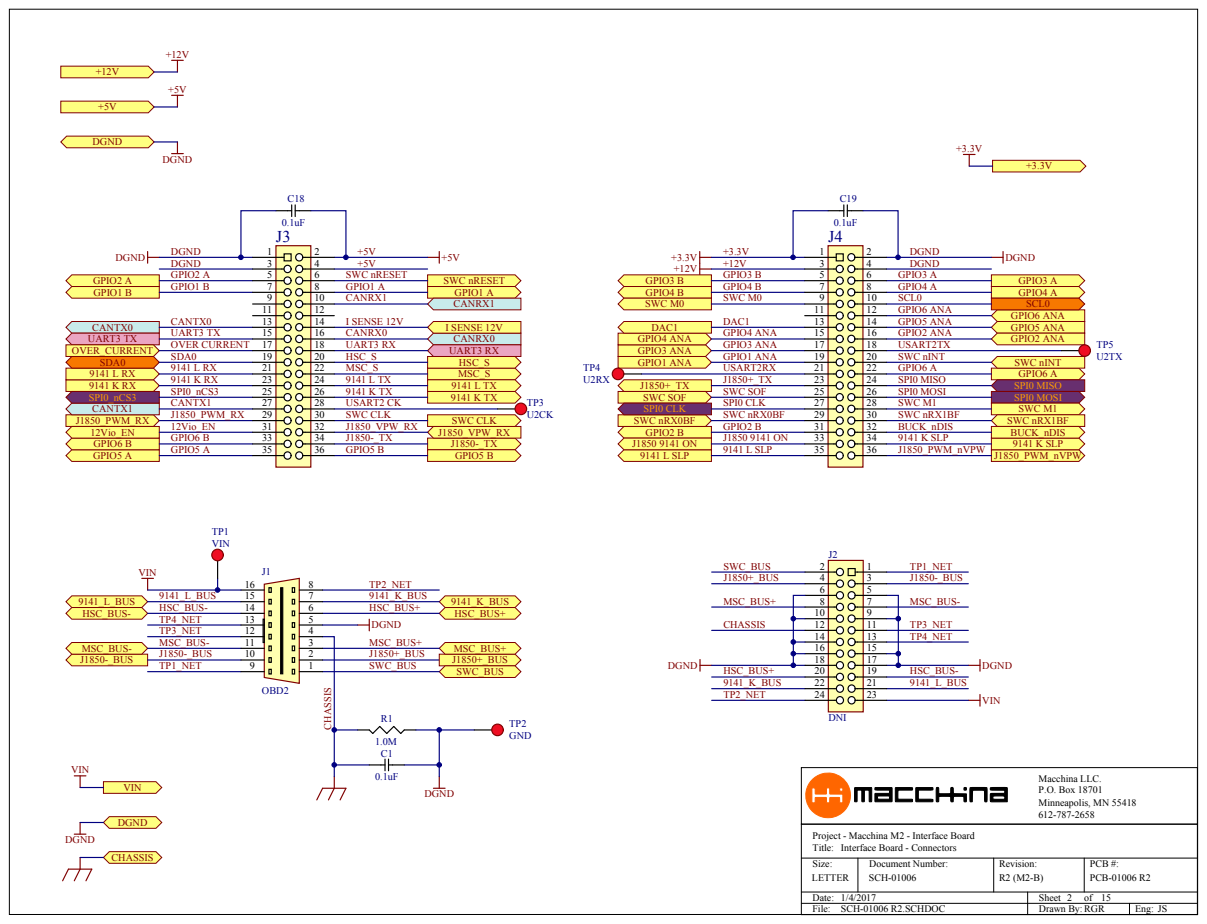
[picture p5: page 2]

Project - Macchina M2 - Interface Board
Title:

# Protection Circuit

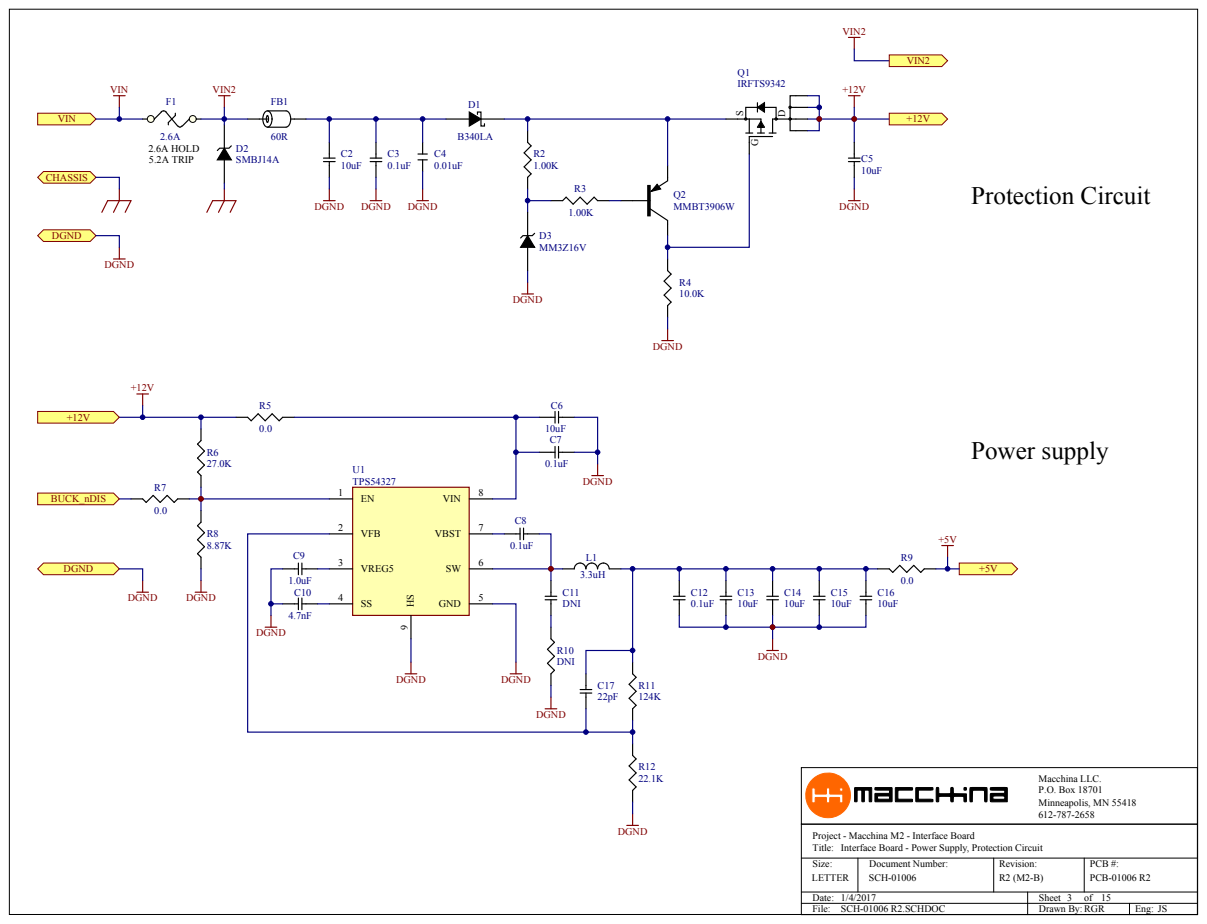
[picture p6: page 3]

Project - Macchina M2 - Interface Board
Title:

Interface Board - Power Supply, Protection Circuit

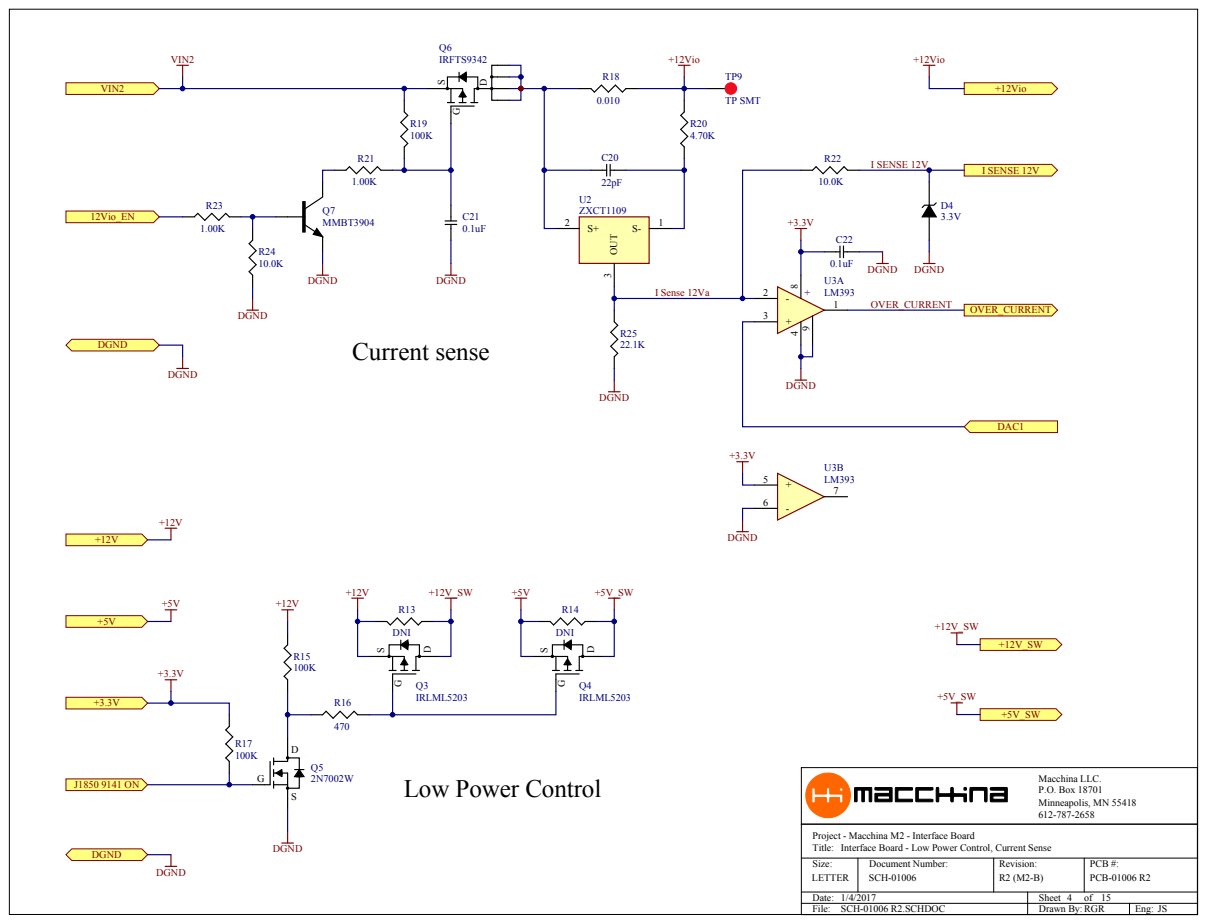
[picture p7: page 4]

Project - Macchina M2 - Interface Board
Title:

Interface Board - Low Power Control, Current Sense

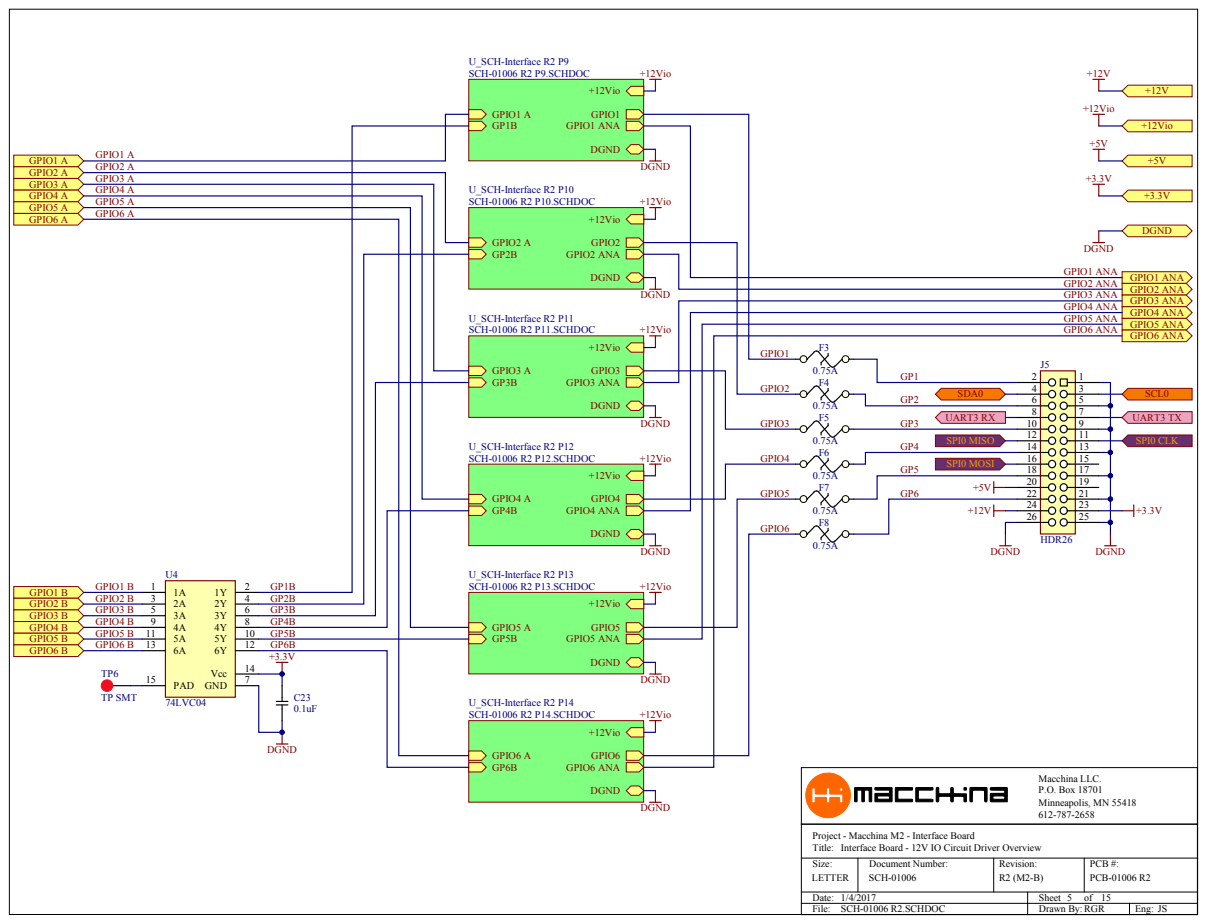
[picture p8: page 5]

Project - Macchina M2 - Interface Board
Title:

Interface Board - 12V IO Circuit Driver Overview

# 12V IO Channel 1

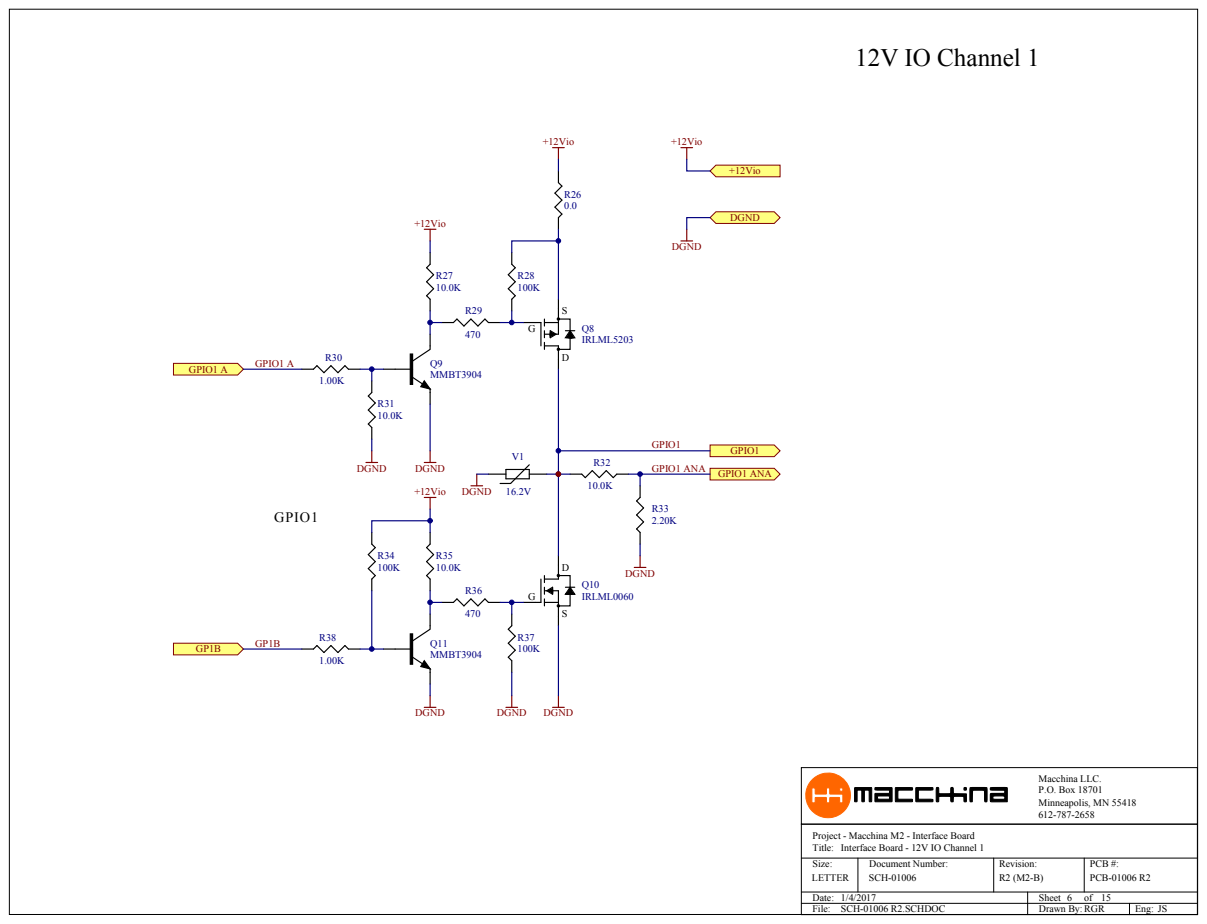
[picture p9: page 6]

Project - Macchina M2 - Interface Board
Title:

Interface Board - 12V IO Channel 1

# 12V IO Channel 2

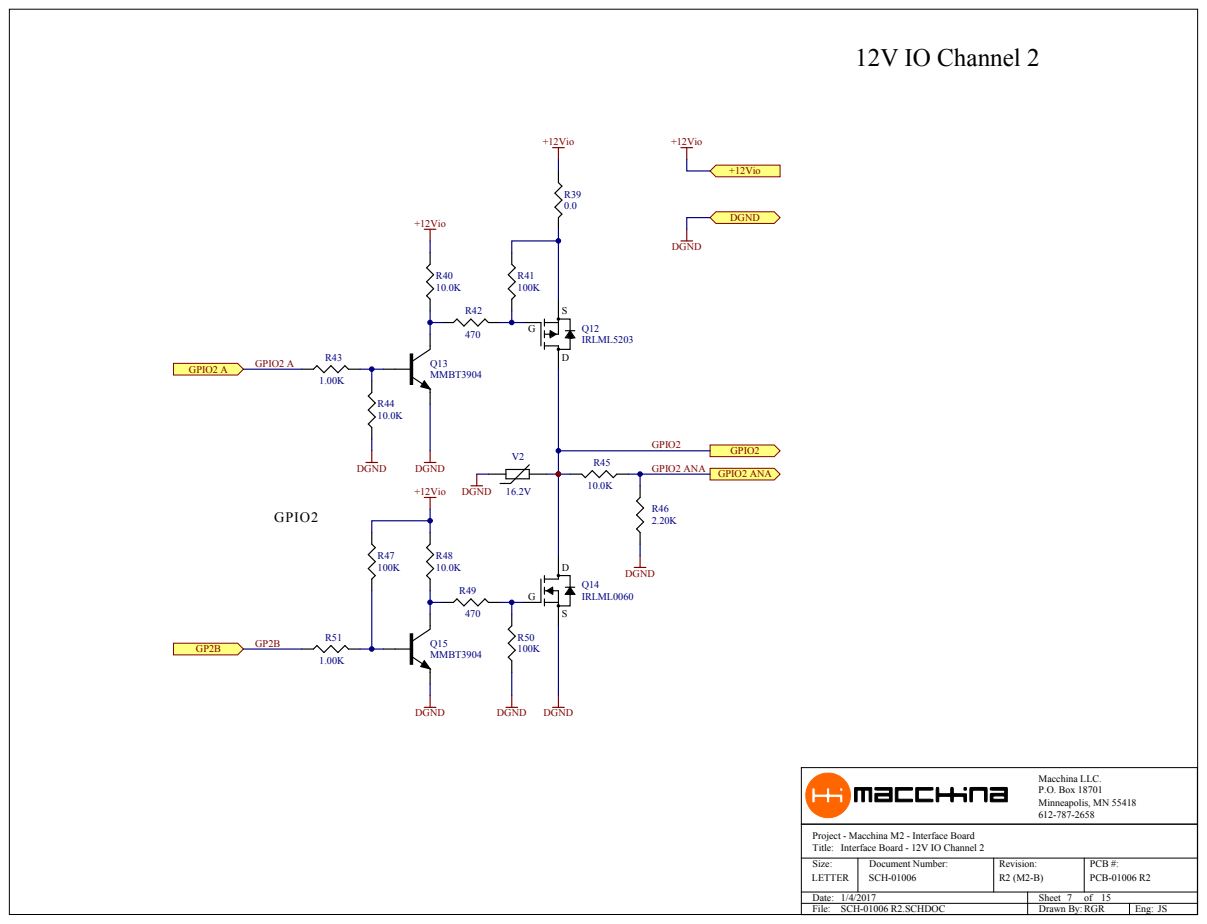
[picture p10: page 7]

Project - Macchina M2 - Interface Board
Title:

Interface Board - 12V IO Channel 2

# 12V IO Channel 3

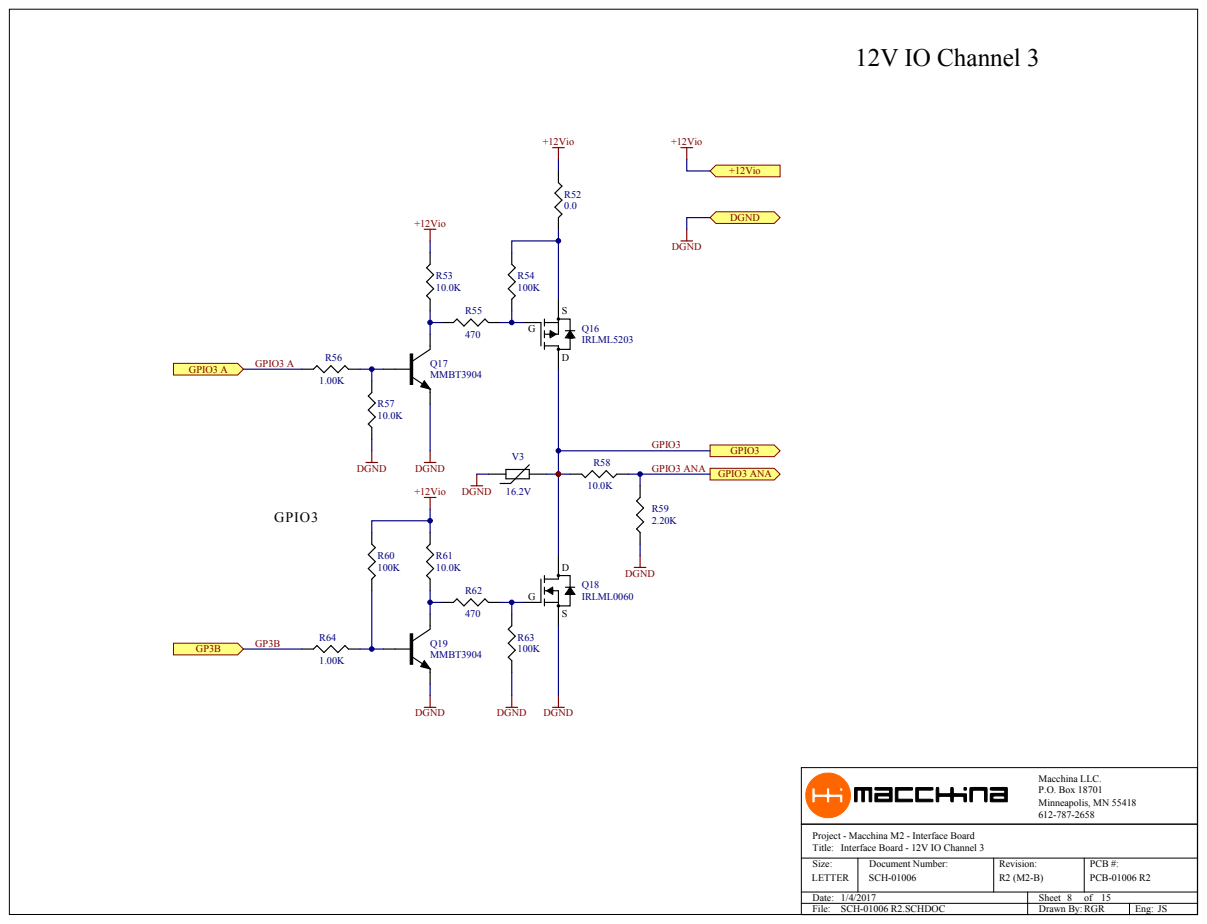
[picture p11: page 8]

Project - Macchina M2 - Interface Board
Title:

Interface Board - 12V IO Channel 3

# 12V IO Channel 4

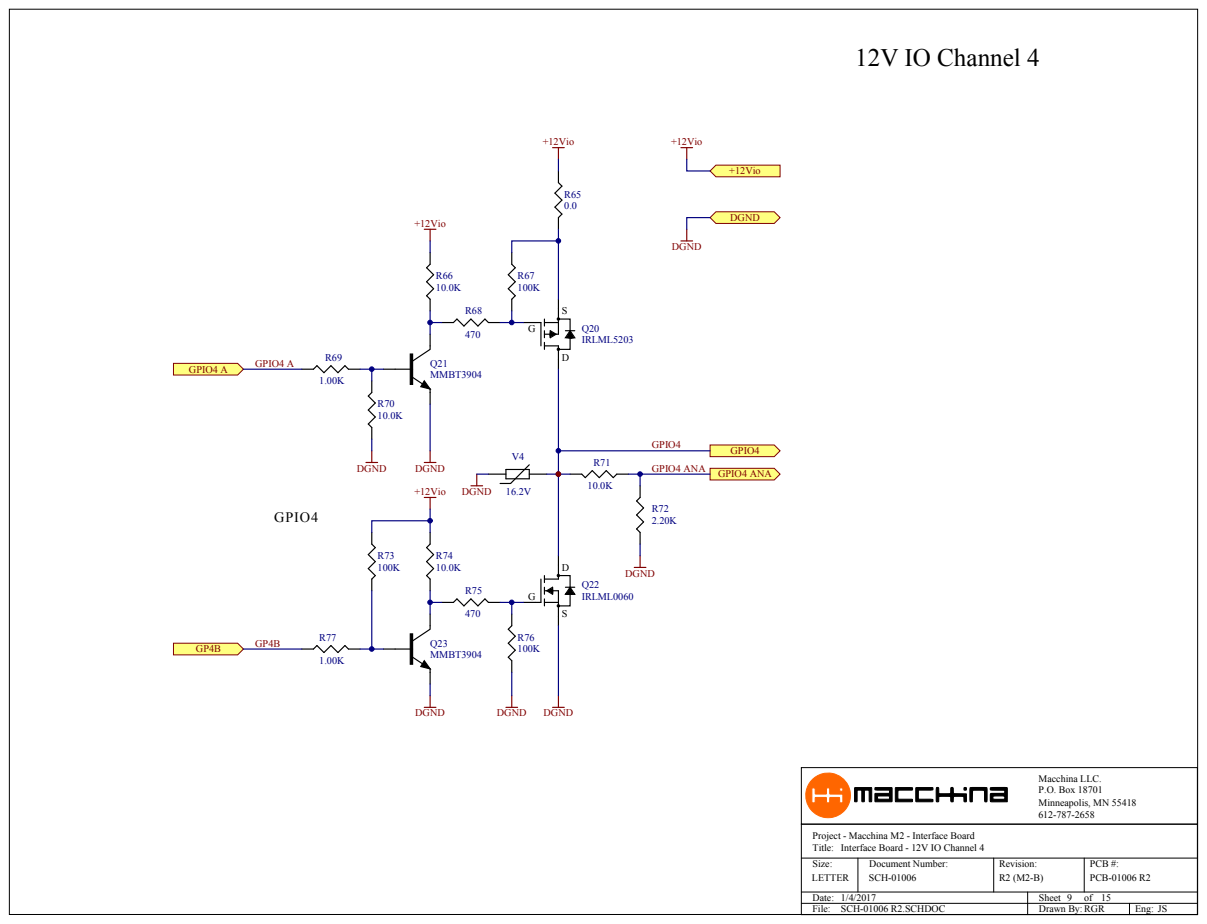
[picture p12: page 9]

Project - Macchina M2 - Interface Board
Title:

Interface Board - 12V IO Channel 4

# 12V IO Channel 5

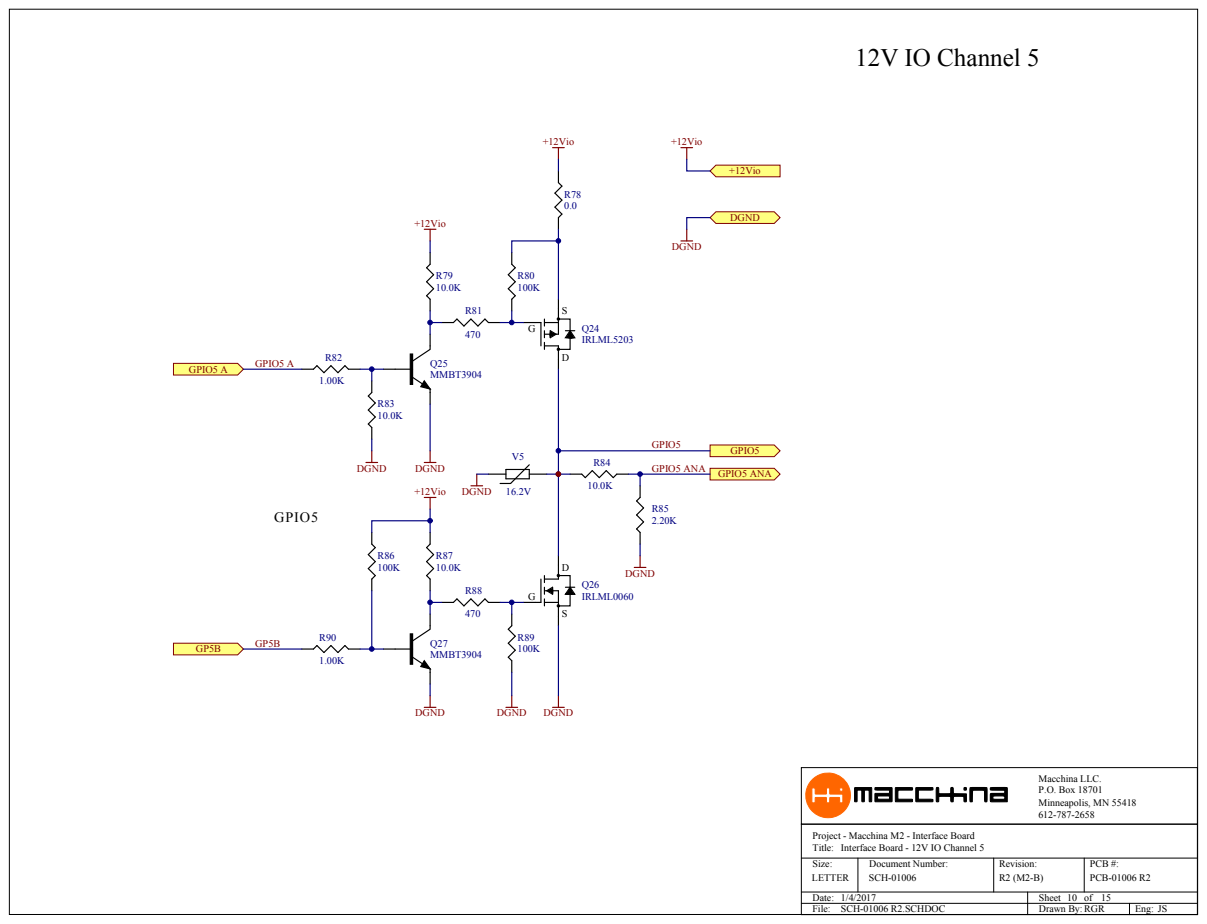
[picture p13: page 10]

Project - Macchina M2 - Interface Board
Title:

Interface Board - 12V IO Channel 5

# 12V IO Channel 6


Project - Macchina M2 - Interface Board
Title:

Interface Board - 12V IO Channel 6

# J1850 PWM/VPW Interfaces


Project - Macchina M2 - Interface Board
Title:

Interface Board - J1850 PWM/VPW Interface

# ISO 9141 / LIN Interface

19 (RX1)


Project - Macchina M2 - Interface Board
Title:

Interface Board - ISO9141/LIN Interfaces

# CAN Interfaces

### CAN0


Project - Macchina M2 - Interface Board
Title:

Interface Board - CAN Interfaces

# Single Wire CAN


Project - Macchina M2 - Interface Board
Title:

Interface Board - Single Wire CAN Interface

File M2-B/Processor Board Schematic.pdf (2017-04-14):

DGND; CANRX0; UART3 RX; SDA0; USART2 CK; M_nRST; OVER CURRENT; HSC_S; GPIO5 B GPIO6 B; 12Vio_EN; J1850_VPW_RX; SWC CLK; GPIO5 A GPIO6 A; J1850_PWM_RX; MSC_S; CANTX0; UART3 TX; CANTX1; SPI0_nCS3; GPIO1 A; GPIO2 B; GPIO3 A GPIO4 A; GPIO5 ANA GPIO6 ANA; 9141 L SLP; SWC nINT; CANRX1; SPI0 MISO SPI0 MOSI; USART2TX; SWC nRX0BF; GPIO1 B; GPIO2 A; GPIO3 B GPIO4 B; GPIO1 ANA GPIO2 ANA GPIO3 ANA GPIO4 ANA; 9141 K SLP; BUCK_nDIS; SWC M1; SWC M0; SWC SOF; SWC nRX1BF; SCL0; DAC1; SPI0 CLK; USART2RX; J1850_PWM_nVPW; VIN; I SENSE 12V; Bridge Connectors to Interface Board; +3.3V LDO Regulator Circuit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

Macchina hardware is released under Creative Commons Share-alike 4.0 International.

Note: This is a human-readable summary of (and not a substitute for) the license.

You are free to:

Share — copy and redistribute the material in any medium or format. Adapt — remix, transform, and build upon the material for any purpose, even commercially. The licensor cannot revoke these freedoms as long as you follow the license terms. Under the following terms:

Attribution — You must give appropriate credit, provide a link to the license, and indicate if changes were made. You may do so in any reasonable manner, but not in any way that suggests the licensor endorses you or your use. ShareAlike — If you remix, transform, or build upon the material, you must distribute your contributions under the same license as the original. No additional restrictions — You may not apply legal terms or technological measures that legally restrict others from doing anything the license permits. Notices:

You do not have to comply with the license for elements of the material in the public domain or where your use is permitted by an applicable exception or limitation. No warranties are given. The license may not give you all of the permissions necessary for your intended use. For example, other rights such as publicity, privacy, or moral rights may limit how you use the material.

Title:; Size:; Document Number:; Revision:; PCB #:; Date: File:; Sheet Drawn By:; Eng:; LETTER; SCH-01005; PCB-01005 R2; SCH-01005 R2.SCHDOC; RGR; Processor Board - Overview; Project - Macchina M2 - Processor Board; P.O. Box 18701; Macchina LLC.; Minneapolis, MN 55418

C40

0.1uF

DGND; CANRX0 UART3 RX; SDA0; 9141 L TX 9141 K TX USART2 CK; OVER CURRENT; HSC_S; GPIO5 B; GPIO6 B; 12Vio_EN; J1850_VPW_RX; SWC CLK; GPIO5 A; J1850_PWM_RX; MSC_S; CANTX0 UART3 TX; CANTX1; SPI0_nCS3; GPIO1 B; GPIO1 A; GPIO2 A; USART2 CK SWC CLK; UART3 RX; CANRX0; M_nRST; SPI0_nCS3 CANTX1; I SENSE 12V; CANRX1 CANRX1; GPIO6 A; GPIO2 B; GPIO3 A GPIO4 A; GPIO5 ANA; GPIO6 ANA; 9141 L SLP; SWC nINT; SPI0 MISO SPI0 MOSI; USART2TX; VIN; SWC nRX0BF; GPIO3 B GPIO4 B; GPIO1 ANA; GPIO2 ANA; GPIO3 ANA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

Project - Macchina M2 - Processor Board
Title:

Processor Board - Bridge Connectors to Interface Board


Processor bulk and bypass caps

Project - Macchina M2 - Processor Board
Title:


Project - Macchina M2 - Processor Board
Title:

Processor Board - USB, OTG and LDO Circuits

## ACTIVE-LOW

# USER BUTTON 1


Project - Macchina M2 - Processor Board
Title:

Processor Board - Switches, LEDs


Directions relative to uC DGND

Project - Macchina M2 - Processor Board
Title:

Processor Board - XBEE, SD, EEPROM Circuits

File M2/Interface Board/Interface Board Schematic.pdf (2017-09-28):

Size:; Document Number:; Revision:; PCB #:; Sheet Drawn By:; Eng:; LETTER; SCH-01006; PCB-01006 R3; RGR; P.O. Box 18701; Macchina LLC.; Minneapolis, MN 55418; J1850-_BUS; J1850+_BUS; 9141_L_BUS; 9141_K_BUS; SWC_BUS; MSC_BUS-; MSC_BUS+; HSC_BUS+ HSC_BUS-; VIN DGND CHASSIS; DGND; VIN2; +5V BUCK_nDIS; GPIO5 A GPIO6 A; J1850_PWM_RX; MSC_S; CANTX0; UART3 TX; CANTX1; SPI0_nCS3; GPIO5 B GPIO6 B; 12Vio_EN; J1850_VPW_RX; HSC_S; SWC CLK; SWC nRESET; CANRX0; UART3 RX SDA0; GPIO1 A; GPIO2 B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

ODB Input Connectors
SCH-01006 R3 P2.SchDoc

Reverse Voltage and Surge Protection Circuit
SCH-01006 R3 P3.SCHDOC
VIN
CHASSIS

Bridge Connectors to Main board Processor
SCH-01006 R3 P5.SCHDOC

12V to 5V DC-DC Converter
SCH-01006 R3 P4.SCHDOC

High Current Driver Circuits
SCH-01006 R3 P8.SCHDOC

DGND
LIN Interface Circuit
SCH-01006 R3 P17.SCHDOC
9141_K_BUS

SCH-01006 R3 P18.SCHDOC
9141_L_BUS

Macchina hardware is released under Creative Commons Share-alike
4.0 International.

High Speed CAN Interface Circuit
SCH-01006 R3 P19.SCHDOC
HSC_BUS+
HSC_BUS-

Note: This is a human-readable summary of (and not a substitute for) the
license.

You are free to:

Share — copy and redistribute the material in any medium or format. Adapt —
remix, transform, and build upon the material for any purpose, even
commercially. The licensor cannot revoke these freedoms as long as you follow
the license terms. Under the following terms:

Medium Speed CAN Interface Circuit
SCH-01006 R3 P20.SCHDOC
MSC_BUS+
MSC_BUS-

Attribution — You must give appropriate credit, provide a link to the license,
and indicate if changes were made. You may do so in any reasonable manner,
but not in any way that suggests the licensor endorses you or your use.
ShareAlike — If you remix, transform, or build upon the material, you must
distribute your contributions under the same license as the original. No
additional restrictions — You may not apply legal terms or technological
measures that legally restrict others from doing anything the license permits.
Notices:

CAN Interface Circuit
SCH-01006 R3 P21.SCHDOC
SWC_BUS

You do not have to comply with the license for elements of the material in the
public domain or where your use is permitted by an applicable exception or
limitation. No warranties are given. The license may not give you all of the
permissions necessary for your intended use. For example, other rights such as
publicity, privacy, or moral rights may limit how you use the material.

Project - Macchina M2 - Interface Board
Title:
Interface Board - Overview
Date:
File:
SCH-01006 R3.SCHDOC

J3
J4


Minneapolis, MN 55418 CHASSIS CHASSIS

Project - Macchina M2 - Interface Board
Title:

# Protection Circuit


Project - Macchina M2 - Interface Board
Title:

Interface Board - Power Supply, Protection Circuit


Project - Macchina M2 - Interface Board
Title:

Interface Board - Low Power Control, Current Sense


Project - Macchina M2 - Interface Board
Title:

Interface Board - 12V IO Circuit Driver Overview

# 12V IO Channel 1 (High Side)


Project - Macchina M2 - Interface Board
Title:

Interface Board - 12V IO Channel 1

# 12V IO Channel 2 (High Side)


Project - Macchina M2 - Interface Board
Title:

Interface Board - 12V IO Channel 2

# 12V IO Channel 3 (High Side)


Project - Macchina M2 - Interface Board
Title:

Interface Board - 12V IO Channel 3

# 12V IO Channel 4 (Low Side)


Project - Macchina M2 - Interface Board
Title:

Interface Board - 12V IO Channel 4

# 12V IO Channel 5 (Low Side)


Project - Macchina M2 - Interface Board
Title:

Interface Board - 12V IO Channel 5

# 12V IO Channel 6 (Low Side)


Project - Macchina M2 - Interface Board
Title:

Interface Board - 12V IO Channel 6

## GPIO1 R32

## GPIO4


Project - Macchina M2 - Interface Board
Title:

Interface Board - Analog Inputs

# J1850 PWM/VPW Interfaces

# J1850-_TX ADJ 1 OUT 2 IN 3


Project - Macchina M2 - Interface Board
Title:

Interface Board - J1850 PWM/VPW Interface

# ISO 9141 / LIN Interface


Project - Macchina M2 - Interface Board
Title:

Interface Board - ISO9141/LIN Interfaces

# CAN Interfaces

# CAN0


Project - Macchina M2 - Interface Board
Title:

Interface Board - CAN Interfaces
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

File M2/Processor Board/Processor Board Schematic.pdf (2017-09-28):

DGND; CANRX0; UART3 RX; SDA0; USART2 CK; M_nRST; OVER CURRENT; HSC_S; GPIO5 B GPIO6 B; 12Vio_EN; J1850_VPW_RX; SWC CLK; GPIO5 A GPIO6 A; J1850_PWM_RX; MSC_S; CANTX0; UART3 TX; CANTX1; SPI0_nCS3; GPIO1 A; GPIO2 B; GPIO3 A GPIO4 A; GPIO5 ANA GPIO6 ANA; 9141 L SLP; SWC nINT; CANRX1; SPI0 MISO SPI0 MOSI; USART2TX; SWC nRX0BF; GPIO1 B; GPIO2 A; GPIO3 B GPIO4 B; GPIO1 ANA GPIO2 ANA GPIO3 ANA GPIO4 ANA; 9141 K SLP; BUCK_nDIS; SWC M1; SWC M0; SWC SOF; SWC nRX1BF; SCL0; DAC1; SPI0 CLK; USART2RX; J1850_PWM_nVPW; VIN; I SENSE 12V; XB_UART TX XB_UART RX ERASE_CMD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

Title:
Size: | Document Number: | Revision: | PCB #:

Date:
File:

Sheet
Drawn By:
| | | of
Eng:
LETTER | SCH-01005 | R3 | PCB-01005 R3

SCH-01005 R3.SCHDOC

RGR | JS

Processor Board - Overview

Project - Macchina M2 - Processor Board

P.O. Box 18701

Macchina LLC.

612-787-2658

Minneapolis, MN 55418

Macchina hardware is released under Creative Commons Share-alike 4.0 International.

Note: This is a human-readable summary of (and not a substitute for) the license.

You are free to:

Share — copy and redistribute the material in any medium or format. Adapt — remix, transform, and build upon the material for any purpose, even commercially. The licensor cannot revoke these freedoms as long as you follow the license terms. Under the following terms:

Attribution — You must give appropriate credit, provide a link to the license, and indicate if changes were made. You may do so in any reasonable manner, but not in any way that suggests the licensor endorses you or your use. ShareAlike — If you remix, transform, or build upon the material, you must distribute your contributions under the same license as the original. No additional restrictions — You may not apply legal terms or technological measures that legally restrict others from doing anything the license permits. Notices:

You do not have to comply with the license for elements of the material in the public domain or where your use is permitted by an applicable exception or limitation. No warranties are given. The license may not give you all of the permissions necessary for your intended use. For example, other rights such as publicity, privacy, or moral rights may limit how you use the material.

P.O. Box 18701; Macchina LLC.; Minneapolis, MN 55418; DGND; CANRX0 UART3 RX; SDA0; 9141 L TX 9141 K TX USART2 CK; OVER CURRENT; HSC_S; GPIO5 B; GPIO6 B; 12Vio_EN; J1850_VPW_RX; SWC CLK; GPIO5 A; J1850_PWM_RX; MSC_S; CANTX0 UART3 TX; CANTX1; SPI0_nCS3; GPIO1 B; GPIO1 A; GPIO2 A; USART2 CK SWC CLK; UART3 RX; CANRX0; M_nRST; SPI0_nCS3 CANTX1; CONN RCPT36; I SENSE 12V; CANRX1 CANRX1; XB_UART TX; XB_UART RX; M_nRST M_nRST; GPIO6 A; GPIO2 B; GPIO3 A GPIO4 A; GPIO5 ANA; GPIO6 ANA; 9141 L SLP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

Project - Macchina M2 - Processor Board
Title:

Processor Board - Bridge Connectors to Interface Board


Processor bulk and bypass caps

Project - Macchina M2 - Processor Board
Title:


Project - Macchina M2 - Processor Board
Title:

Processor Board - USB, OTG and LDO Circuits

## ACTIVE-LOW

# USER BUTTON 1


Project - Macchina M2 - Processor Board
Title:

Processor Board - Switches, LEDs


Project - Macchina M2 - Processor Board
Title:

Processor Board - XBEE, SD, EEPROM Circuits

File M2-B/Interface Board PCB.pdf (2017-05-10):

Size:; Document Number:; Revision:; PCB #:; Sheet Drawn By:; Eng:; LETTER; PCB-01006; PCB-01006 R2; RGR; P.O. Box 18701; Macchina LLC.; Minneapolis, MN 55418; Layer 1: Top; Layer 2: Mid 1; Layer 3: Mid 2; Layer 4: Bottom 1

Project - Macchina M2 - Interface Board
Title:
Date:
File:

Interface Board - PCB Layers

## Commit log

2017-04-14 schematic/locator initial release
2017-05-10 Adding PCB layer files
2017-09-28 Adding R3 (release) Schematic
2018-05-09 Adding Gerbers for both Processor and Interface
    [PCB-01005 R3.GBL, PCB-01005 R3.GBO, PCB-01005 R3.GBP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]
2020-09-30 Adding BOMs
    [BOM-PCB-01015 R1.csv, BOM-PCB-01016 R1.csv]
